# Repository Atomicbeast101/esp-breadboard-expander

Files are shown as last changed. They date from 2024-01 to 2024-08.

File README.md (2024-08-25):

# ESP Breadboard Expander

Kicad-designed ESP32/ESP8266/ESP-01S breadboard expander PCB with built-in external power supply. This is to provide the option for connecting these ESP chips to the standard breadboards with a separate power supply to provide enough current for prototyping. This DC power supply also powers the ESP chip too.

This PCB was designed as my first project to understand the whole designing process as well as the JLCPCB ordering part. It has gone through 2 revisions to get it working properly.

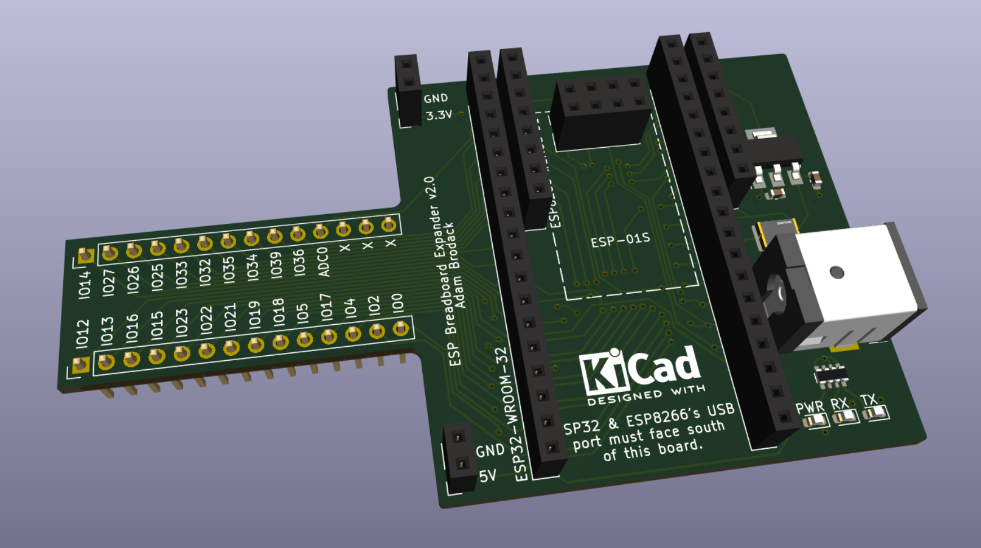
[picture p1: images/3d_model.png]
3D Model


## Specifications

* It uses a 5V DC (5.5 x 2.5mm) power supply to power the board, can use an AC to DC power supply or USB to DC jack cable to power this PCB board.
* Uses a specific ESP32 chip (ESP-WROOM-32; [Amazon Link](https://www.amazon.com/gp/product/B0B764YL3J)) to fit on this board. Other variations would most likely not fit the ESP32 slot.

## Schematic

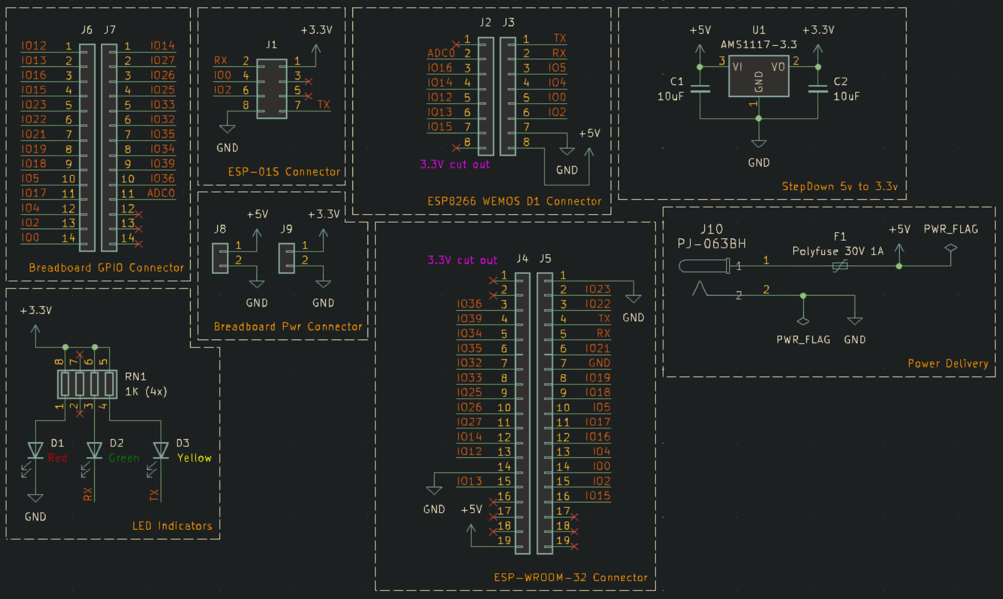
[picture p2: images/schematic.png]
Schematic


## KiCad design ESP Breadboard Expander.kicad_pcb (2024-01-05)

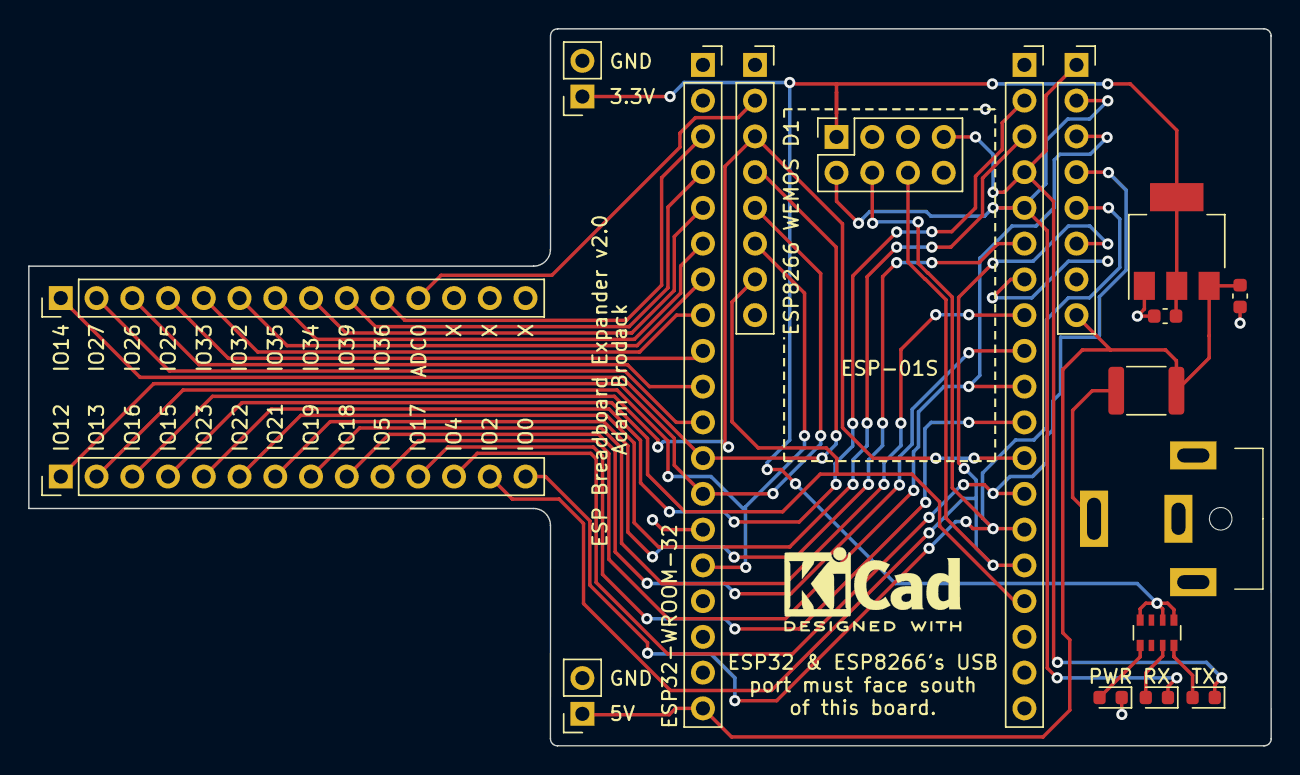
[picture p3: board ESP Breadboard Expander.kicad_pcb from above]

Board: 4 copper layers, 88.3 x 50.9 mm, 18 parts (0 on the bottom side), 34 nets.

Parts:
C1, C2: 10uF; C_0603_1608Metric
D1: Red; LED_0603_1608Metric
D2: Green; LED_0603_1608Metric
D3: Yellow; LED_0603_1608Metric
F1: Polyfuse 30V 1A; Fuse_1812_4532Metric
J1: Conn_02x04_Odd_Even; PinSocket_2x04_P2.54mm_Vertical
J2, J3: Conn_01x08_Socket; PinSocket_1x08_P2.54mm_Vertical
J4, J5: Conn_01x19_Socket; PinSocket_1x19_P2.54mm_Vertical
J6, J7: Conn_01x14_Pin; PinHeader_1x14_P2.54mm_Vertical_UpSideDown
J8, J9: Conn_01x02_Socket; PinSocket_1x02_P2.54mm_Vertical
J10: PJ-063BH; DC_Power_Jack_PJ-063BH
RN1: 1K (4x); R_Array_Convex_4x0603
U1: AMS1117-3.3; SOT-223-3_TabPin2

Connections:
+3.3V: C2.1, J1.1, J9.1, RN1.5 (R4.2), RN1.6 (R3.2), RN1.8 (R1.2), U1.2 (VO)
+5V: C1.1, F1.2, J3.8, J4.19, J8.1, U1.3 (VI)
/ADC0: J2.2, J7.11
/IO0: J1.4, J3.5, J5.14, J6.14
/IO2: J1.6, J3.6, J5.15, J6.13
/IO4: J3.4, J5.13, J6.12
/IO5: J3.3, J5.10, J6.10
/IO12: J2.5, J4.13, J6.1
/IO13: J2.6, J4.15, J6.2
/IO14: J2.4, J4.12, J7.1
/IO15: J2.7, J5.16, J6.4
/IO16: J2.3, J5.12, J6.3
/IO17: J5.11, J6.11
/IO18: J5.9, J6.9
/IO19: J5.8, J6.8
/IO21: J5.6, J6.7
/IO22: J5.3, J6.6
/IO23: J5.2, J6.5
/IO25: J4.9, J7.4
/IO26: J4.10, J7.3
/IO27: J4.11, J7.2
/IO32: J4.7, J7.6
/IO33: J4.8, J7.5
/IO34: J4.5, J7.8
/IO35: J4.6, J7.7
/IO36: J4.3, J7.10
/IO39: J4.4, J7.9
/RX: D2.1 (K), J1.2, J3.2, J5.5
/TX: D3.1 (K), J1.7, J3.1, J5.4
GND: C1.2, C2.2, D1.1 (K), J1.8, J3.7, J4.14, J5.1, J5.7, J8.2, J9.2, J10.2, U1.1 (GND)
unnamed: D1.2 (A), RN1.1 (R1.1)
unnamed: D2.2 (A), RN1.3 (R3.1)
unnamed: D3.2 (A), RN1.4 (R4.1)
unnamed: F1.1, J10.1

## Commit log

2023-12-25 Fixed position of labels
    [ESP Breadboard Expander.kicad_pcb]
2023-12-26 Removed diode for 3.3V power from ESP to breadboard
    [ESP Breadboard Expander.kicad_pcb, ESP Breadboard Expander.kicad_sch]
2023-12-26 Improved GND traces
    [ESP Breadboard Expander.kicad_pcb]
2023-12-27 Added more labeling & checked some JLCPCB capabilities
    [ESP Breadboard Expander.kicad_pcb]
2023-12-27 Fixed all errors found by DRC
    [ESP Breadboard Expander.kicad_pcb]
2023-12-28 Fixed a number of issues to work with JLCPCB
    [ESP Breadboard Expander-CuBottom.gbr, ESP Breadboard Expander-CuIn1.gbr, ESP Breadboard Expander-CuIn2.gbr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]
2024-01-05 Fixed LED circuit & position of them
    [ESP Breadboard Expander.kicad_pcb, ESP Breadboard Expander.kicad_sch]
2024-01-05 Updated JLCPCB Files
    [ESP Breadboard Expander-CuBottom.gbr, ESP Breadboard Expander-CuIn1.gbr, ESP Breadboard Expander-CuIn2.gbr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]
2024-01-05 Fixed position of order #
    [ESP Breadboard Expander-CuBottom.gbr, ESP Breadboard Expander-CuIn1.gbr, ESP Breadboard Expander-CuIn2.gbr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]
2024-08-25 Added README details
    [ESP Breadboard Expander.kicad_sch]
2024-08-25 Removed jlcpcb/ folder
    [ESP Breadboard Expander-CuBottom.gbr, ESP Breadboard Expander-CuIn1.gbr, ESP Breadboard Expander-CuIn2.gbr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]
2024-08-28 Updated schematic to look nicer
